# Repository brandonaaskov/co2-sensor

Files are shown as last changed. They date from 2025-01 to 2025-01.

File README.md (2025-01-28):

# CO2 Sensor

## Crappy Wiring Diagram
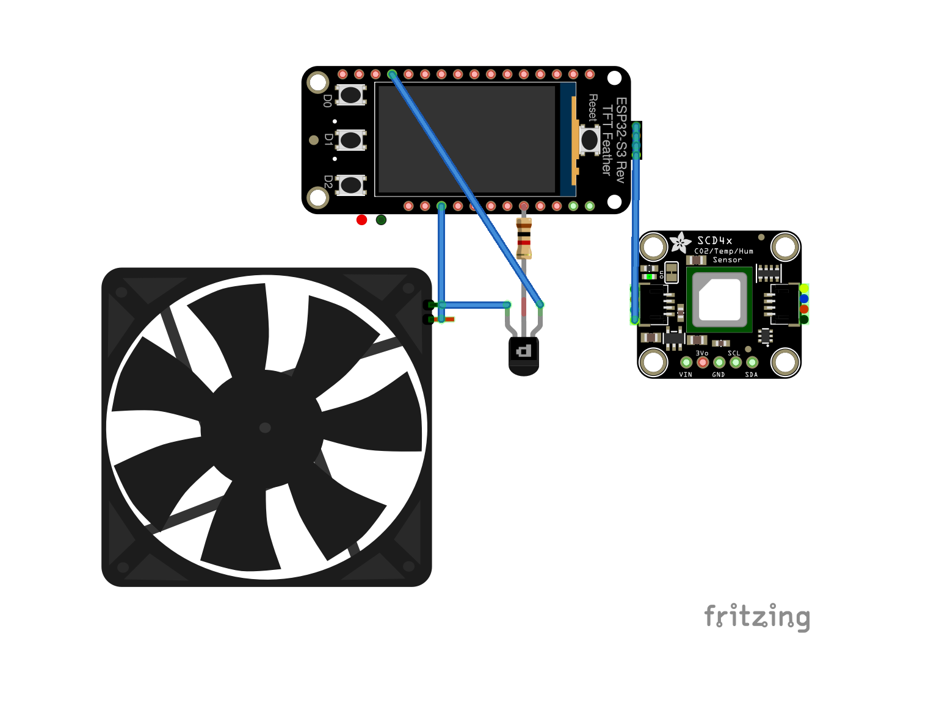
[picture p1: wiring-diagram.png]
Wiring Diagram


## Parts List

This uses a [PN2222A transistor](https://cdn-shop.adafruit.com/datasheets/PN2222A.pdf).

- [Microcontroller: Adafruit ESP32-S3 Reverse TFT Feather](https://www.adafruit.com/product/5691)
- [Adafruit CO2 Sensor](https://www.adafruit.com/product/5187)
- [PN2222A Transistor](https://www.adafruit.com/product/756)
- 1KΩ resistor
- Computer Fan: 5V 90mA
  - _does not need variable control_
  - _5V is required, low current draw allows the board to power it all_
  - _if total current draw from fans exceeds 500mA, a separate power supply is required_

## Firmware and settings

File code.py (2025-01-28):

import board
import terminalio
import time
from adafruit_display_text import bitmap_label
import displayio
import adafruit_scd4x
import digitalio

# Initialize I2C
i2c = board.I2C()
scd4x = adafruit_scd4x.SCD4X(i2c)
scd4x.start_periodic_measurement()

# Initialize fan control GPIO
fan_pin = digitalio.DigitalInOut(board.D9)
fan_pin.direction = digitalio.Direction.OUTPUT
fan_pin.drive_mode = digitalio.DriveMode.PUSH_PULL
fan_pin.value = False  # Start with fan off (normal logic)

display = board.DISPLAY

# Create the main display group
main_group = displayio.Group()

# Create the PPM text (large and centered)
ppm_text = bitmap_label.Label(terminalio.FONT, text="Wait...", scale=3, color=0xFF0000)
ppm_text.anchor_point = (0.5, 0.5)
ppm_text.anchored_position = (display.width // 2, display.height // 2)

# Create the clock text (smaller, bottom right)
clock_text = bitmap_label.Label(terminalio.FONT, text="00:00:00", scale=1)
clock_text.x = display.width - 70
clock_text.y = display.height - 10

# Create fan status text (smaller, top right)
fan_text = bitmap_label.Label(terminalio.FONT, text="Fan: OFF", scale=1)
fan_text.x = display.width - 70
fan_text.y = 20

# Add all elements to the main group
main_group.append(ppm_text)
main_group.append(clock_text)
main_group.append(fan_text)

# Show it on the display
display.root_group = main_group

# Variables for fan control with hysteresis
FAN_ON_THRESHOLD = 1100

while True:
    print(fan_pin.value)
    # Update the time
    current_time = time.localtime()
    time_str = "{:02d}:{:02d}:{:02d}".format(
        current_time.tm_hour, current_time.tm_min, current_time.tm_sec
    )
    clock_text.text = time_str

    # Read CO2 data if it's available
    if scd4x.data_ready:
        co2 = scd4x.CO2
        ppm_text.text = f"{co2} ppm"

        # Fan control logic with hysteresis (normal logic)
        if co2 > FAN_ON_THRESHOLD:  # Check if fan is off
            fan_pin.value = True  # Turn fan on
            fan_text.text = "Fan: ON"
        else:  # Check if fan is on
            fan_pin.value = False  # Turn fan off
            fan_text.text = "Fan: OFF"

        # Color coding based on CO2 levels
        if co2 < FAN_ON_THRESHOLD:
            ppm_text.color = 0x00FF00  # Green
        elif co2 < 1500:
            ppm_text.color = 0xFFFF00  # Yellow
        else:
            ppm_text.color = 0xFF0000  # Red

    time.sleep(1)

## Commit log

2025-01-28 second AI prompt, also failed
    At this point I tested some sample code from the adafruit libraries to get some basics working and was able to prove that out.
2025-01-28 adds CO2 sensor (still Claude-only)
    Pretty impressed with how it handled this prompt
2025-01-28 adds computer fan (Claude-only)
    code kinda works, but not exactly...
    Hindsight: using a MOSFET was overkill, and a PN2222A transistor ended up being the trick. They both work the same way, I'm just switching far lower voltage/amperage than the MOSFET would have been u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
2025-01-28 the final prototype (AI-assisted)
2025-01-28 adds Fritzing wiring diagram and image for README
    [wiring-diagram.fzz]
2025-01-28 adds some whitespace to the wiring diagram
2025-01-28 simplest version in working order
    The feather board has a "USB" pin on it that delivers 5V+, which is all I needed to power this single fan. That allowed me to remove the PowerBoost 500 Basic that I had in between.
    When I had a separate power supply for most of this work, the ground of the feather was not shared with the ground of everything else. Remove the extra power supply fixed this issue, but I'm still not sure the proper way to get around that in the future.
    [code.py]
